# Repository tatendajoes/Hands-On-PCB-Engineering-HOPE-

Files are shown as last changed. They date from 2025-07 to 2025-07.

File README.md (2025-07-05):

# USB Charger PCB
**Mentor:** Nehemiah Edison  
**Mentee:** Tatenda Joseph

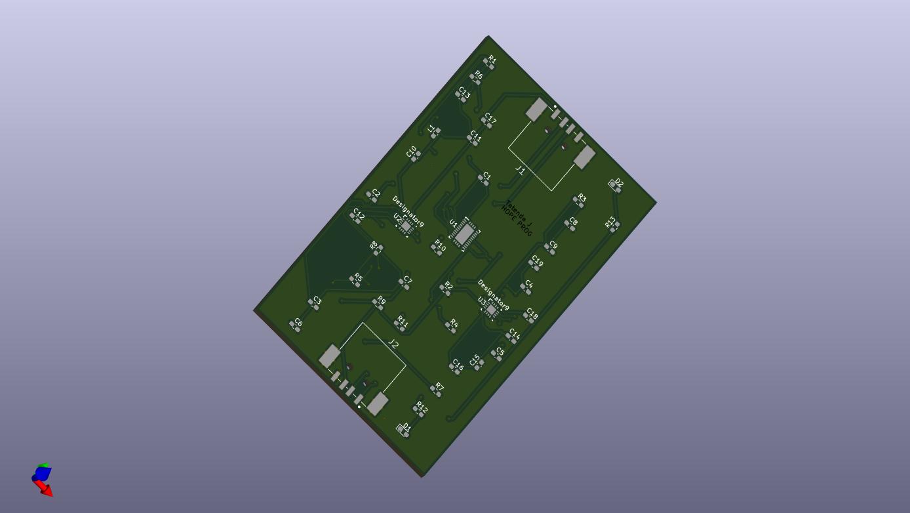
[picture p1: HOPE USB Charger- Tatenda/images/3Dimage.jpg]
3D diagram of USB charger PCB

## Overview
The project focuses on designing and developing a USB charger PCB. The primary function is to provide a regulated 5 V DC supply to charge USB devices (smartphones, tablets, etc.).

## How It Works
1. **12 V DC Input**: Accepts 12 V DC from a car battery, bench supply, or external adapter.  
2. **5 V Buck Conversion (LM73606)**: Synchronous step-down converter steps 12 V down to a regulated 5 V rail (up to 6 A).  
3. **USB Charging Port Controllers (TPS2549 × 2)**: Each USB-A port uses a TPS2549 for BC1.2 signature detection (SDP/CDP/DCP), allowing up to 1.5 A per port.  
4. **Dual-Port Output**: Each port supplies 5 V at 1.5 A (7.5 W), with both ports up to 3 A total (15 W).

## Components
- Capacitors (various values) – 19 total  
- LEDs (BLUE CLEAR SMD R/A) – 2  
- USB Connectors – 2  
- Inductor (Iron-core) – 1  
- Resistors (various values and types) – 13 total  
- LM73606 switching regulator IC – 1  
- TPS2549 IC (BC1.2 port controller) – 2

## Use Cases
- Charging smartphones and tablets (BC1.2-compliant devices, up to 1.5 A)  
- Powering USB modules (Arduinos, ESP32, Raspberry Pi Zero, sensors)  
- Converting 12 V to 5 V for bench or automotive applications

## Objectives
- Design schematic in KiCad and assign footprints  
- Run ERC and complete PCB layout  
- Run DRC and generate Gerbers  
- Create BOM and submit to Oshpark  
- Order parts from DigiKey and assemble PCB  
- Test and validate performance

## Schematic

- Schematic Diagram
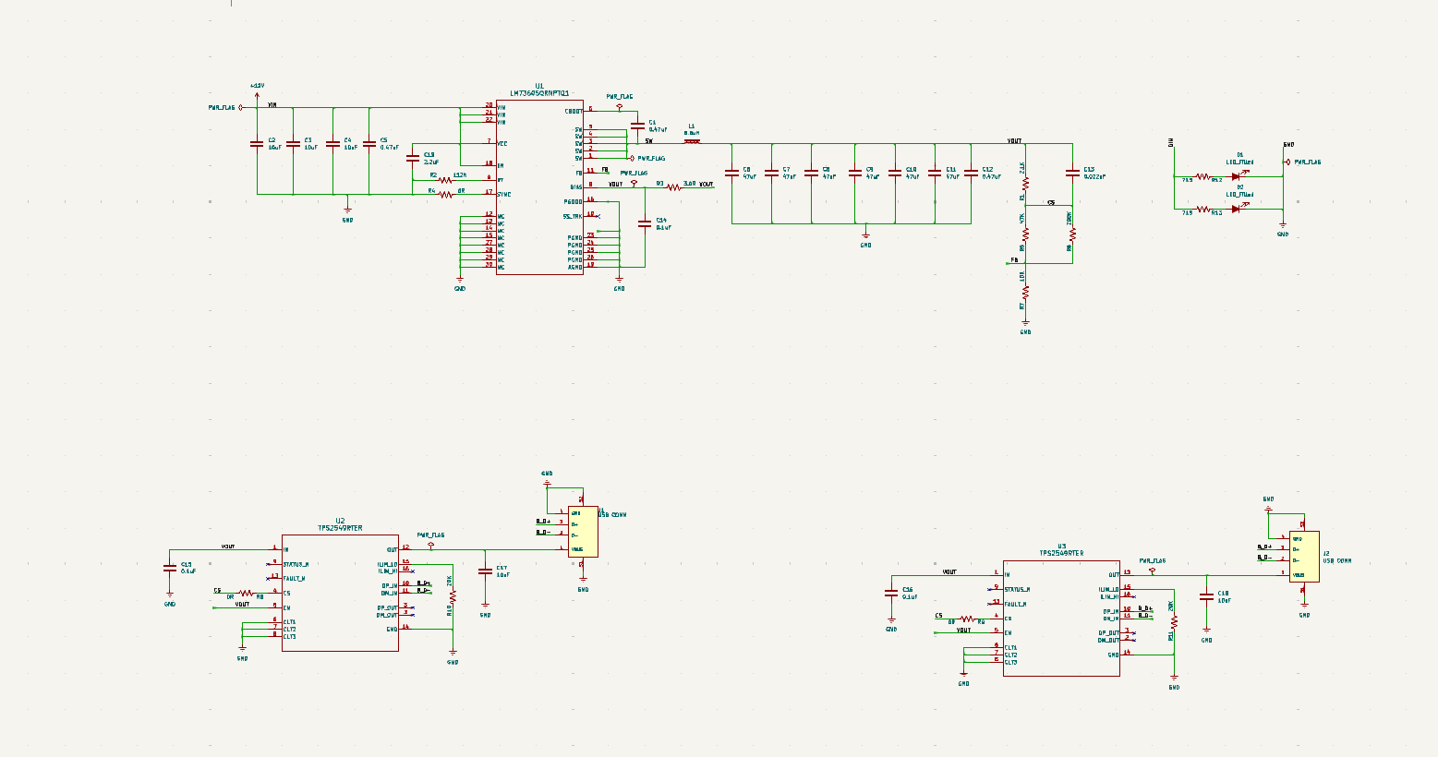
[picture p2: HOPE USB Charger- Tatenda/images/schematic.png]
shematic diagram of USB charger PCB


- PCB Diagram
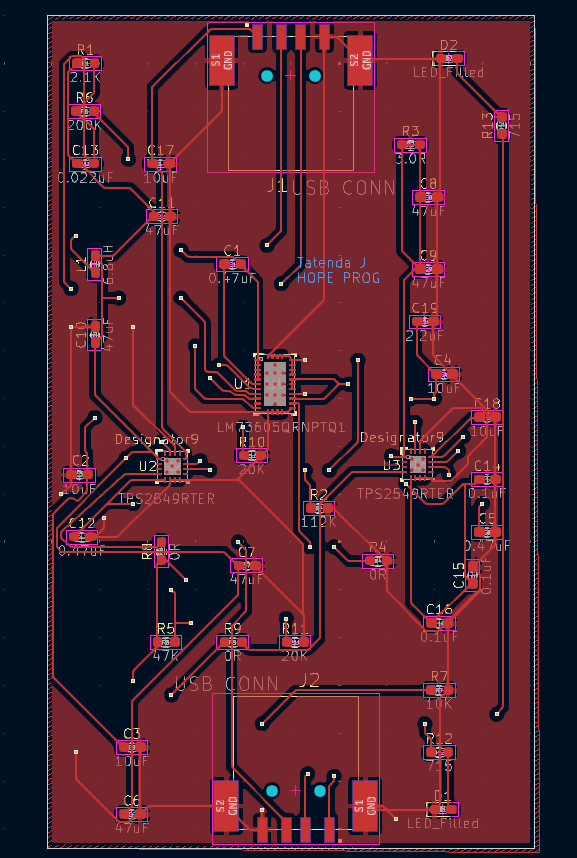
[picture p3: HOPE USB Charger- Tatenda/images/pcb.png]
pcb diagram of USB charger PCB


## Specifications
| Parameter | Specification |
|---|---|
| **Input** | |
| Voltage range | 9 – 18 V DC |
| Maximum input current | 4 A (at Vin under full load)  |
| **Power Conversion**  | |
| Converter IC | LM73606 |
| Typical efficiency | ~90% at 3 A |
| **Output (per port)** | |
| Voltage | 5.00 V ± 1% |
| Max current | 1.5 A |
| **Combined output** | |
| Total max current | 3.0 A |
| **Port controller** | |
| Controller IC | TPS2549 × 2 |
| BC1.2 signatures | SDP / CDP / DCP |
| **Environmental** | |
| Operating temperature | –40 °C to +85 °C |
| **PCB** | |
| Layers & material | 2-layer FR-4 (1.6 mm) |
| Dimensions | 60 mm × 40 mm (approx.) |

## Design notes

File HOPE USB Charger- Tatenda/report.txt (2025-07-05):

Info: Processing symbol 'C1:Capacitor_SMD:C_0603_1608Metric_Pad1.08x0.95mm_HandSolder'.
Info: Processing symbol 'C14:Capacitor_SMD:C_0603_1608Metric_Pad1.08x0.95mm_HandSolder'.
Info: Processing symbol 'C4:Capacitor_SMD:C_0603_1608Metric_Pad1.08x0.95mm_HandSolder'.
Info: Processing symbol 'C13:Capacitor_SMD:C_0603_1608Metric_Pad1.08x0.95mm_HandSolder'.
Info: Processing symbol 'C9:Capacitor_SMD:C_0603_1608Metric_Pad1.08x0.95mm_HandSolder'.
Info: Processing symbol 'C8:Capacitor_SMD:C_0603_1608Metric_Pad1.08x0.95mm_HandSolder'.
Info: Processing symbol 'C10:Capacitor_SMD:C_0603_1608Metric_Pad1.08x0.95mm_HandSolder'.
Info: Processing symbol 'C7:Capacitor_SMD:C_0603_1608Metric_Pad1.08x0.95mm_HandSolder'.
Info: Processing symbol 'C3:Capacitor_SMD:C_0603_1608Metric_Pad1.08x0.95mm_HandSolder'.
Info: Processing symbol 'C19:Capacitor_SMD:C_0603_1608Metric_Pad1.08x0.95mm_HandSolder'.
Info: Processing symbol 'C6:Capacitor_SMD:C_0603_1608Metric_Pad1.08x0.95mm_HandSolder'.
Info: Processing symbol 'C11:Capacitor_SMD:C_0603_1608Metric_Pad1.08x0.95mm_HandSolder'.
Info: Processing symbol 'C15:Capacitor_SMD:C_0603_1608Metric_Pad1.08x0.95mm_HandSolder'.
Info: Processing symbol 'C2:Capacitor_SMD:C_0603_1608Metric_Pad1.08x0.95mm_HandSolder'.
Info: Processing symbol 'C18:Capacitor_SMD:C_0603_1608Metric_Pad1.08x0.95mm_HandSolder'.
Info: Processing symbol 'C5:Capacitor_SMD:C_0603_1608Metric_Pad1.08x0.95mm_HandSolder'.
Info: Processing symbol 'C12:Capacitor_SMD:C_0603_1608Metric_Pad1.08x0.95mm_HandSolder'.
Info: Processing symbol 'C16:Capacitor_SMD:C_0603_1608Metric_Pad1.08x0.95mm_HandSolder'.
Info: Processing symbol 'C17:Capacitor_SMD:C_0603_1608Metric_Pad1.08x0.95mm_HandSolder'.
Info: Processing symbol 'D1:Diode_SMD:D_0603_1608Metric_Pad1.05x0.95mm_HandSolder'.
Info: Processing symbol 'D2:Diode_SMD:D_0603_1608Metric_Pad1.05x0.95mm_HandSolder'.
Info: Processing symbol 'J1:AAMU Senior Design 2024-25:CUI_UJ2-AH-1-SMT'.
Info: Processing symbol 'J2:AAMU Senior Design 2024-25:CUI_UJ2-AH-1-SMT'.
Info: Processing symbol 'L1:Inductor_SMD:L_0603_1608Metric_Pad1.05x0.95mm_HandSolder'.
Info: Processing symbol 'R1:Resistor_SMD:R_0603_1608Metric_Pad0.98x0.95mm_HandSolder'.
Info: Processing symbol 'R2:Resistor_SMD:R_0603_1608Metric_Pad0.98x0.95mm_HandSolder'.
Info: Processing symbol 'R3:Resistor_SMD:R_0603_1608Metric_Pad0.98x0.95mm_HandSolder'.
Info: Processing symbol 'R4:Resistor_SMD:R_0603_1608Metric_Pad0.98x0.95mm_HandSolder'.
Info: Processing symbol 'R5:Resistor_SMD:R_0603_1608Metric_Pad0.98x0.95mm_HandSolder'.
Info: Processing symbol 'R6:Resistor_SMD:R_0603_1608Metric_Pad0.98x0.95mm_HandSolder'.
Info: Processing symbol 'R7:Resistor_SMD:R_0603_1608Metric_Pad0.98x0.95mm_HandSolder'.
Info: Processing symbol 'R8:Resistor_SMD:R_0603_1608Metric_Pad0.98x0.95mm_HandSolder'.
Info: Processing symbol 'R9:Resistor_SMD:R_0603_1608Metric_Pad0.98x0.95mm_HandSolder'.
Info: Processing symbol 'R10:Resistor_SMD:R_0603_1608Metric_Pad0.98x0.95mm_HandSolder'.
Info: Processing symbol 'R11:Resistor_SMD:R_0603_1608Metric_Pad0.98x0.95mm_HandSolder'.
Info: Processing symbol 'R12:Resistor_SMD:R_0603_1608Metric_Pad0.98x0.95mm_HandSolder'.
Info: Processing symbol 'R13:Resistor_SMD:R_0603_1608Metric_Pad0.98x0.95mm_HandSolder'.
Info: Processing symbol 'U1:AAMU Senior Design 2024-25:RNP0030A'.
Info: Processing symbol 'U2:AAMU Senior Design 2024-25:RTE0016C'.
Info: Processing symbol 'U3:AAMU Senior Design 2024-25:RTE0016C'.
Connected C2 pin 2 to GND.
Add net +12V.
Connected C2 pin 1 to +12V.
Added C3 (footprint 'Capacitor_SMD:C_0603_1608Metric_Pad1.08x0.95mm_HandSolder').
Changed REF** reference designator to C3.
Changed C3 value from C_0603_1608Metric_Pad1.08x0.95mm_HandSolder to 10uF.
Updated C3 symbol association from  to /19286bda-7a7a-4466-992b-d0f40b0c6c4e.
Updated C3 fields.
Updated C3 sheetname to 'Root'.
Updated C3 sheetfile to 'HOPE USB Charger- Tatenda.kicad_sch'.
Updated C3 footprint filters to 'C_*'.
Connected C3 pin 1 to +12V.
Connected C3 pin 2 to GND.
Added C4 (footprint 'Capacitor_SMD:C_0603_1608Metric_Pad1.08x0.95mm_HandSolder').
Changed REF** reference designator to C4.
Changed C4 value from C_0603_1608Metric_Pad1.08x0.95mm_HandSolder to 10uF.
Updated C4 symbol association from  to /04ccd5c6-15b2-4030-945e-ed818584f25c.
Updated C4 fields.
Updated C4 sheetname to 'Root'.
Updated C4 sheetfile to 'HOPE USB Charger- Tatenda.kicad_sch'.
Updated C4 footprint filters to 'C_*'.
Connected C4 pin 1 to +12V.
Connected C4 pin 2 to GND.
Added C5 (footprint 'Capacitor_SMD:C_0603_1608Metric_Pad1.08x0.95mm_HandSolder').
Changed REF** reference designator to C5.
Changed C5 value from C_0603_1608Metric_Pad1.08x0.95mm_HandSolder to 0.47uF.
Updated C5 symbol association from  to /ef5993d3-073b-4f01-b6a1-0fe2b9706ae6.
Updated C5 fields.
Updated C5 sheetname to 'Root'.
Updated C5 sheetfile to 'HOPE USB Charger- Tatenda.kicad_sch'.
Updated C5 footprint filters to 'C_*'.
Connected C5 pin 1 to +12V.
Connected C5 pin 2 to GND.
Added C6 (footprint 'Capacitor_SMD:C_0603_1608Metric_Pad1.08x0.95mm_HandSolder').
Changed REF** reference designator to C6.
Changed C6 value from C_0603_1608Metric_Pad1.08x0.95mm_HandSolder to 47uF.
Updated C6 symbol association from  to /00fe3671-6971-4a1d-9a66-dda608e3093a.
Updated C6 fields.
Updated C6 sheetname to 'Root'.
Updated C6 sheetfile to 'HOPE USB Charger- Tatenda.kicad_sch'.
Updated C6 footprint filters to 'C_*'.
Connected C6 pin 2 to GND.
Add net /VOUT.
Connected C6 pin 1 to /VOUT.
Added C7 (footprint 'Capacitor_SMD:C_0603_1608Metric_Pad1.08x0.95mm_HandSolder').
Changed REF** reference designator to C7.
Changed C7 value from C_0603_1608Metric_Pad1.08x0.95mm_HandSolder to 47uF.
Updated C7 symbol association from  to /8db145ac-a443-40e6-a1bf-7e9539908e10.
Updated C7 fields.
Updated C7 sheetname to 'Root'.
Updated C7 sheetfile to 'HOPE USB Charger- Tatenda.kicad_sch'.
Updated C7 footprint filters to 'C_*'.
Connected C7 pin 1 to /VOUT.
Connected C7 pin 2 to GND.
Added C8 (footprint 'Capacitor_SMD:C_0603_1608Metric_Pad1.08x0.95mm_HandSolder').
Changed REF** reference designator to C8.
Changed C8 value from C_0603_1608Metric_Pad1.08x0.95mm_HandSolder to 47uF.
Updated C8 symbol association from  to /60575305-37fa-4438-99a9-70368577a35f.
Updated C8 fields.
Updated C8 sheetname to 'Root'.
Updated C8 sheetfile to 'HOPE USB Charger- Tatenda.kicad_sch'.
Updated C8 footprint filters to 'C_*'.
Connected C8 pin 1 to /VOUT.
Connected C8 pin 2 to GND.
Added C9 (footprint 'Capacitor_SMD:C_0603_1608Metric_Pad1.08x0.95mm_HandSolder').
Changed REF** reference designator to C9.
Changed C9 value from C_0603_1608Metric_Pad1.08x0.95mm_HandSolder to 47uF.
Updated C9 symbol association from  to /c17b6783-4fc2-4924-acce-468ea2bac7e7.
Updated C9 fields.
Updated C9 sheetname to 'Root'.
Updated C9 sheetfile to 'HOPE USB Charger- Tatenda.kicad_sch'.
Updated C9 footprint filters to 'C_*'.
Connected C9 pin 2 to GND.
Connected C9 pin 1 to /VOUT.
Added C10 (footprint 'Capacitor_SMD:C_0603_1608Metric_Pad1.08x0.95mm_HandSolder').
Changed REF** reference designator to C10.
Changed C10 value from C_0603_1608Metric_Pad1.08x0.95mm_HandSolder to 47uF.
Updated C10 symbol association from  to /0f25906a-1385-4035-a5d8-c43b97dbfe95.
Updated C10 fields.
Updated C10 sheetname to 'Root'.
Updated C10 sheetfile to 'HOPE USB Charger- Tatenda.kicad_sch'.
Updated C10 footprint filters to 'C_*'.
Connected C10 pin 2 to GND.
Connected C10 pin 1 to /VOUT.
Added C11 (footprint 'Capacitor_SMD:C_0603_1608Metric_Pad1.08x0.95mm_HandSolder').
Changed REF** reference designator to C11.
Changed C11 value from C_0603_1608Metric_Pad1.08x0.95mm_HandSolder to 47uF.
Updated C11 symbol association from  to /2349d69c-5e6f-4ee1-b4f1-8996a50e921d.
Updated C11 fields.
Updated C11 sheetname to 'Root'.
Updated C11 sheetfile to 'HOPE USB Charger- Tatenda.kicad_sch'.
Updated C11 footprint filters to 'C_*'.
Connected C11 pin 1 to /VOUT.
Connected C11 pin 2 to GND.
Added C12 (footprint 'Capacitor_SMD:C_0603_1608Metric_Pad1.08x0.95mm_HandSolder').
Changed REF** reference designator to C12.
Changed C12 value from C_0603_1608Metric_Pad1.08x0.95mm_HandSolder to 0.47uF.
Updated C12 symbol association from  to /210c44ad-f5fc-4b04-afed-6277b7e008d1.
Updated C12 fields.
Updated C12 sheetname to 'Root'.
Updated C12 sheetfile to 'HOPE USB Charger- Tatenda.kicad_sch'.
Updated C12 footprint filters to 'C_*'.
Connected C12 pin 2 to GND.
Connected C12 pin 1 to /VOUT.
Added C13 (footprint 'Capacitor_SMD:C_0603_1608Metric_Pad1.08x0.95mm_HandSolder').
Changed REF** reference designator to C13.
Changed C13 value from C_0603_1608Metric_Pad1.08x0.95mm_HandSolder to 0.022uF.
Updated C13 symbol association from  to /689d0605-5dd5-4adc-8e06-5128acd837bf.
Updated C13 fields.
Updated C13 sheetname to 'Root'.
Updated C13 sheetfile to 'HOPE USB Charger- Tatenda.kicad_sch'.
Updated C13 footprint filters to 'C_*'.
Connected C13 pin 1 to /VOUT.
Add net /CS.
Connected C13 pin 2 to /CS.
Added C14 (footprint 'Capacitor_SMD:C_0603_1608Metric_Pad1.08x0.95mm_HandSolder').
Changed REF** reference designator to C14.
Changed C14 value from C_0603_1608Metric_Pad1.08x0.95mm_HandSolder to 0.1uF.
Updated C14 symbol association from  to /54368b59-0083-4ce2-8e27-e1faf3f807eb.
Updated C14 fields.
Updated C14 sheetfile to 'HOPE USB Charger- Tatenda.kicad_sch'.
Updated C14 footprint filters to 'C_*'.
Connected C14 pin 1 to /VOUT.
Connected C14 pin 2 to GND.
Added C15 (footprint 'Capacitor_SMD:C_0603_1608Metric_Pad1.08x0.95mm_HandSolder').
Changed REF** reference designator to C15.
Changed C15 value from C_0603_1608Metric_Pad1.08x0.95mm_HandSolder to 0.1uF.
Updated C15 symbol association from  to /e1a83c1a-e9d5-4eb2-84d7-cf7e96ed6b5c.
Updated C15 fields.
Updated C15 sheetname to 'Root'.
Updated C15 sheetfile to 'HOPE USB Charger- Tatenda.kicad_sch'.
Updated C15 footprint filters to 'C_*'.
Connected C15 pin 1 to /VOUT.
Connected C15 pin 2 to GND.
Added C16 (footprint 'Capacitor_SMD:C_0603_1608Metric_Pad1.08x0.95mm_HandSolder').
Changed REF** reference designator to C16.
Changed C16 value from C_0603_1608Metric_Pad1.08x0.95mm_HandSolder to 0.1uF.
Updated C16 symbol association from  to /3e55ec13-5c51-4087-b657-3464082d02a5.
Updated C16 fields.
Updated C16 sheetname to 'Root'.
Updated C16 sheetfile to 'HOPE USB Charger- Tatenda.kicad_sch'.
Updated C16 footprint filters to 'C_*'.
Connected C16 pin 1 to /VOUT.
Connected C16 pin 2 to GND.
Added C17 (footprint 'Capacitor_SMD:C_0603_1608Metric_Pad1.08x0.95mm_HandSolder').
Changed REF** reference designator to C17.
Changed C17 value from C_0603_1608Metric_Pad1.08x0.95mm_HandSolder to 10uF.
Updated C17 symbol association from  to /3fcb8ce3-75a4-4dc4-8ae5-304c34109ee5.
Updated C17 fields.
Updated C17 sheetname to 'Root'.
Updated C17 sheetfile to 'HOPE USB Charger- Tatenda.kicad_sch'.
Updated C17 footprint filters to 'C_*'.
Connected C17 pin 2 to GND.
Add net Net-(J1-VBUS).
Connected C17 pin 1 to Net-(J1-VBUS).
Added C18 (footprint 'Capacitor_SMD:C_0603_1608Metric_Pad1.08x0.95mm_HandSolder').
Changed REF** reference designator to C18.
Changed C18 value from C_0603_1608Metric_Pad1.08x0.95mm_HandSolder to 10uF.
Updated C18 symbol association from  to /bf8fe8a2-7e39-4c4e-be99-1289ef0bbc39.
Updated C18 fields.
Updated C18 sheetname to 'Root'.
Updated C18 sheetfile to 'HOPE USB Charger- Tatenda.kicad_sch'.
Updated C18 footprint filters to 'C_*'.
Add net Net-(J2-VBUS).
Connected C18 pin 1 to Net-(J2-VBUS).
Connected C18 pin 2 to GND.
Updated C14 sheetname to 'Root'.
Added C19 (footprint 'Capacitor_SMD:C_0603_1608Metric_Pad1.08x0.95mm_HandSolder').
Changed REF** reference designator to C19.
Changed C19 value from C_0603_1608Metric_Pad1.08x0.95mm_HandSolder to 2.2uF.
Updated C19 symbol association from  to /f62714eb-9b48-4dca-be03-ad18b1f4418e.
Updated C19 fields.
Updated C19 sheetname to 'Root'.
Updated C19 sheetfile to 'HOPE USB Charger- Tatenda.kicad_sch'.
Updated C19 footprint filters to 'C_*'.
Connected C19 pin 2 to GND.
Connected C19 pin 1 to +12V.
Added C1 (footprint 'Capacitor_SMD:C_0603_1608Metric_Pad1.08x0.95mm_HandSolder').
Added D1 (footprint 'Diode_SMD:D_0603_1608Metric_Pad1.05x0.95mm_HandSolder').
Changed REF** reference designator to D1.
Changed D1 value from D_0603_1608Metric_Pad1.05x0.95mm_HandSolder to LED_Filled.
Updated D1 symbol association from  to /e141c6f9-6236-4e4f-9423-103b54fd7a2f.
Updated D1 fields.
Updated D1 sheetname to 'Root'.
Updated D1 sheetfile to 'HOPE USB Charger- Tatenda.kicad_sch'.
Updated D1 footprint filters to 'LED* LED_SMD:* LED_THT:*'.
Add net Net-(D1-A).
Connected D1 pin 2 to Net-(D1-A).
Connected D1 pin 1 to GND.
Changed REF** reference designator to C1.
Added D2 (footprint 'Diode_SMD:D_0603_1608Metric_Pad1.05x0.95mm_HandSolder').
Changed REF** reference designator to D2.
Changed D2 value from D_0603_1608Metric_Pad1.05x0.95mm_HandSolder to LED_Filled.
Updated D2 symbol association from  to /46838bdf-4686-4594-9151-cc60d0690727.
Updated D2 fields.
Updated D2 sheetname to 'Root'.
Updated D2 sheetfile to 'HOPE USB Charger- Tatenda.kicad_sch'.
Updated D2 footprint filters to 'LED* LED_SMD:* LED_THT:*'.
Add net Net-(D2-A).
Connected D2 pin 2 to Net-(D2-A).
Connected D2 pin 1 to GND.
Changed C1 value from C_0603_1608Metric_Pad1.08x0.95mm_HandSolder to 0.47uF.
Updated C1 symbol association from  to /335372d9-3a5d-4d5a-a8b4-353cd66d1977.
Updated C1 fields.
Added L1 (footprint 'Inductor_SMD:L_0603_1608Metric_Pad1.05x0.95mm_HandSolder').
Changed REF** reference designator to L1.
Changed L1 value from L_0603_1608Metric_Pad1.05x0.95mm_HandSolder to 6.8uH.
Updated L1 symbol association from  to /37fa4ad2-6970-476d-abc9-2c8cad30b114.
Updated L1 fields.
Updated L1 sheetname to 'Root'.
Updated L1 sheetfile to 'HOPE USB Charger- Tatenda.kicad_sch'.
Updated L1 footprint filters to 'Choke_* *Coil* Inductor_* L_*'.
Connected L1 pin 2 to /VOUT.
Connected L1 pin 1 to /SW.
Updated C1 sheetname to 'Root'.
Added R1 (footprint 'Resistor_SMD:R_0603_1608Metric_Pad0.98x0.95mm_HandSolder').
Changed REF** reference designator to R1.
Changed R1 value from R_0603_1608Metric_Pad0.98x0.95mm_HandSolder to 2.1K.
Updated R1 symbol association from  to /0eba38ee-2483-4a1f-a93c-bf059771c4f2.
Updated R1 fields.
Updated R1 sheetname to 'Root'.
Updated R1 sheetfile to 'HOPE USB Charger- Tatenda.kicad_sch'.
Updated R1 footprint filters to 'R_*'.
Connected R1 pin 2 to /CS.
Connected R1 pin 1 to /VOUT.
Updated C1 sheetfile to 'HOPE USB Charger- Tatenda.kicad_sch'.
Added R2 (footprint 'Resistor_SMD:R_0603_1608Metric_Pad0.98x0.95mm_HandSolder').
Changed REF** reference designator to R2.
Changed R2 value from R_0603_1608Metric_Pad0.98x0.95mm_HandSolder to 112K.
Updated R2 symbol association from  to /35ce431e-2ae0-4e6b-9935-65c3c85fc5c0.
Updated R2 fields.
Updated R2 sheetname to 'Root'.
Updated R2 sheetfile to 'HOPE USB Charger- Tatenda.kicad_sch'.
Updated R2 footprint filters to 'R_*'.
Connected R2 pin 2 to GND.
Add net Net-(U1-RT).
Connected R2 pin 1 to Net-(U1-RT).
Updated C1 footprint filters to 'C_*'.
Added R3 (footprint 'Resistor_SMD:R_0603_1608Metric_Pad0.98x0.95mm_HandSolder').
Changed REF** reference designator to R3.
Changed R3 value from R_0603_1608Metric_Pad0.98x0.95mm_HandSolder to 3.0R.
Updated R3 symbol association from  to /b5b9785f-a7e4-41e9-a2fe-aed746a44e0d.
Updated R3 fields.
Updated R3 sheetname to 'Root'.
Updated R3 sheetfile to 'HOPE USB Charger- Tatenda.kicad_sch'.
Updated R3 footprint filters to 'R_*'.
Connected R3 pin 1 to /VOUT.
Connected R3 pin 2 to /VOUT.
Add net Net-(U1-CBOOT).
Added R4 (footprint 'Resistor_SMD:R_0603_1608Metric_Pad0.98x0.95mm_HandSolder').
Changed REF** reference designator to R4.
Changed R4 value from R_0603_1608Metric_Pad0.98x0.95mm_HandSolder to 0R.
Updated R4 symbol association from  to /766dea5a-03ff-4513-90cd-af29e92f0ade.
Updated R4 fields.
Updated R4 sheetname to 'Root'.
Updated R4 sheetfile to 'HOPE USB Charger- Tatenda.kicad_sch'.
Updated R4 footprint filters to 'R_*'.
Add net Net-(U1-SYNC).
Connected R4 pin 1 to Net-(U1-SYNC).
Connected R4 pin 2 to GND.
Connected C1 pin 1 to Net-(U1-CBOOT).
Added R5 (footprint 'Resistor_SMD:R_0603_1608Metric_Pad0.98x0.95mm_HandSolder').
Changed REF** reference designator to R5.
Changed R5 value from R_0603_1608Metric_Pad0.98x0.95mm_HandSolder to 47K.
Updated R5 symbol association from  to /3486b6a7-176e-468b-bf43-bdb705569e36.
Updated R5 fields.
Updated R5 sheetname to 'Root'.
Updated R5 sheetfile to 'HOPE USB Charger- Tatenda.kicad_sch'.
Updated R5 footprint filters to 'R_*'.
Connected R5 pin 1 to /CS.
Add net /FB.
Connected R5 pin 2 to /FB.
Add net /SW.
Added R6 (footprint 'Resistor_SMD:R_0603_1608Metric_Pad0.98x0.95mm_HandSolder').
Changed REF** reference designator to R6.
Changed R6 value from R_0603_1608Metric_Pad0.98x0.95mm_HandSolder to 200K.
Updated R6 symbol association from  to /e81fb007-7ae9-4c03-9c0f-d92360785fff.
Updated R6 fields.
Updated R6 sheetname to 'Root'.
Updated R6 sheetfile to 'HOPE USB Charger- Tatenda.kicad_sch'.
Updated R6 footprint filters to 'R_*'.
Connected R6 pin 2 to /FB.
Connected R6 pin 1 to /CS.
Connected C1 pin 2 to /SW.
Added R7 (footprint 'Resistor_SMD:R_0603_1608Metric_Pad0.98x0.95mm_HandSolder').
Changed REF** reference designator to R7.
Changed R7 value from R_0603_1608Metric_Pad0.98x0.95mm_HandSolder to 10K.
Updated R7 symbol association from  to /892a2c66-8db2-4780-a052-6eef2fc0a6a8.
Updated R7 fields.
Updated R7 sheetname to 'Root'.
Updated R7 sheetfile to 'HOPE USB Charger- Tatenda.kicad_sch'.
Updated R7 footprint filters to 'R_*'.
Connected R7 pin 1 to /FB.
Connected R7 pin 2 to GND.
Added C2 (footprint 'Capacitor_SMD:C_0603_1608Metric_Pad1.08x0.95mm_HandSolder').
Added R8 (footprint 'Resistor_SMD:R_0603_1608Metric_Pad0.98x0.95mm_HandSolder').
Changed REF** reference designator to R8.
Changed R8 value from R_0603_1608Metric_Pad0.98x0.95mm_HandSolder to 0R.
Updated R8 symbol association from  to /d2c124ac-7850-4621-9b2c-24e613d258bc.
Updated R8 fields.
Updated R8 sheetname to 'Root'.
Updated R8 sheetfile to 'HOPE USB Charger- Tatenda.kicad_sch'.
Updated R8 footprint filters to 'R_*'.
Connected R8 pin 1 to /CS.
Add net Net-(U2-CS).
Connected R8 pin 2 to Net-(U2-CS).
Changed REF** reference designator to C2.
Added R9 (footprint 'Resistor_SMD:R_0603_1608Metric_Pad0.98x0.95mm_HandSolder').
Changed REF** reference designator to R9.
Changed R9 value from R_0603_1608Metric_Pad0.98x0.95mm_HandSolder to 0R.
Updated R9 symbol association from  to /f95fb09a-5959-45ad-aa9c-b73250de8db6.
Updated R9 fields.
Updated R9 sheetname to 'Root'.
Updated R9 sheetfile to 'HOPE USB Charger- Tatenda.kicad_sch'.
Updated R9 footprint filters to 'R_*'.
Connected R9 pin 1 to /CS.
Add net Net-(U3-CS).
Connected R9 pin 2 to Net-(U3-CS).
Changed C2 value from C_0603_1608Metric_Pad1.08x0.95mm_HandSolder to 10uF.
Added R10 (footprint 'Resistor_SMD:R_0603_1608Metric_Pad0.98x0.95mm_HandSolder').
Changed REF** reference designator to R10.
Changed R10 value from R_0603_1608Metric_Pad0.98x0.95mm_HandSolder to 20K.
Updated R10 symbol association from  to /c2334109-bf59-453b-b08c-01f0eb29283c.
Updated R10 fields.
Updated R10 sheetname to 'Root'.
Updated R10 sheetfile to 'HOPE USB Charger- Tatenda.kicad_sch'.
Updated R10 footprint filters to 'R_*'.
Connected R10 pin 2 to GND.
Add net Net-(U2-ILIM_LO).
Connected R10 pin 1 to Net-(U2-ILIM_LO).
Updated C2 symbol association from  to /327b265e-bf1d-4c05-9ce4-4cd48b15e5ac.
Added R11 (footprint 'Resistor_SMD:R_0603_1608Metric_Pad0.98x0.95mm_HandSolder').
Changed REF** reference designator to R11.
Changed R11 value from R_0603_1608Metric_Pad0.98x0.95mm_HandSolder to 20K.
Updated R11 symbol association from  to /95875f8f-b52c-4588-a41e-5449f336b5ed.
Updated R11 fields.
Updated R11 sheetname to 'Root'.
Updated R11 sheetfile to 'HOPE USB Charger- Tatenda.kicad_sch'.
Updated R11 footprint filters to 'R_*'.
Connected R11 pin 2 to GND.
Add net Net-(U3-ILIM_LO).
Connected R11 pin 1 to Net-(U3-ILIM_LO).
Updated C2 fields.
Added R12 (footprint 'Resistor_SMD:R_0603_1608Metric_Pad0.98x0.95mm_HandSolder').
Changed REF** reference designator to R12.
Changed R12 value from R_0603_1608Metric_Pad0.98x0.95mm_HandSolder to 715.
Updated R12 symbol association from  to /d5bc29ee-c82b-4fe7-845a-510ada208e56.
Updated R12 fields.
Updated R12 sheetname to 'Root'.
Updated R12 sheetfile to 'HOPE USB Charger- Tatenda.kicad_sch'.
Updated R12 footprint filters to 'R_*'.
Connected R12 pin 2 to Net-(D1-A).
Add net /DIM.
Connected R12 pin 1 to /DIM.
Updated C2 sheetname to 'Root'.
Added R13 (footprint 'Resistor_SMD:R_0603_1608Metric_Pad0.98x0.95mm_HandSolder').
Changed REF** reference designator to R13.
Changed R13 value from R_0603_1608Metric_Pad0.98x0.95mm_HandSolder to 715.
Updated R13 symbol association from  to /5c4f9f64-80ce-4307-932f-d32ab01887b4.
Updated R13 fields.
Updated R13 sheetname to 'Root'.
Updated R13 sheetfile to 'HOPE USB Charger- Tatenda.kicad_sch'.
Updated R13 footprint filters to 'R_*'.
Connected R13 pin 1 to /DIM.
Connected R13 pin 2 to Net-(D2-A).
Updated C2 sheetfile to 'HOPE USB Charger- Tatenda.kicad_sch'.
Updated C2 footprint filters to 'C_*'.
Add net GND.
Error: Cannot add U1 (footprint 'AAMU Senior Design 2024-25:RNP0030A' not found).
Error: Cannot add J2 (footprint 'AAMU Senior Design 2024-25:CUI_UJ2-AH-1-SMT' not found).
Error: Cannot add U2 (footprint 'AAMU Senior Design 2024-25:RTE0016C' not found).
Error: Cannot add J1 (footprint 'AAMU Senior Design 2024-25:CUI_UJ2-AH-1-SMT' not found).
Error: Cannot add U3 (footprint 'AAMU Senior Design 2024-25:RTE0016C' not found).

Info: Total warnings: 0, errors: 5.

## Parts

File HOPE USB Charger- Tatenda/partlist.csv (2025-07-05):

Reference | Value | Datasheet | Footprint | Qty | DNP
C1,C5,C12 | 0.47uF | ~ | Capacitor_SMD:C_0603_1608Metric_Pad1.08x0.95mm_HandSolder | 3
C2,C3,C4,C17,C18 | 10uF | ~ | Capacitor_SMD:C_0603_1608Metric_Pad1.08x0.95mm_HandSolder | 5
C6,C7,C8,C9,C10,C11 | 47uF | ~ | Capacitor_SMD:C_0603_1608Metric_Pad1.08x0.95mm_HandSolder | 6
C13 | 0.022uF | ~ | Capacitor_SMD:C_0603_1608Metric_Pad1.08x0.95mm_HandSolder | 1
C14,C15,C16 | 0.1uF | ~ | Capacitor_SMD:C_0603_1608Metric_Pad1.08x0.95mm_HandSolder | 3
C19 | 2.2uF | ~ | Capacitor_SMD:C_0603_1608Metric_Pad1.08x0.95mm_HandSolder | 1
D1,D2 | LED_Filled | ~ | Diode_SMD:D_0603_1608Metric_Pad1.05x0.95mm_HandSolder | 2
J1,J2 | USB CONN |  | Library:CUI_UJ2-AH-1-SMT | 2
L1 | 6.8uH | ~ | Inductor_SMD:L_0603_1608Metric_Pad1.05x0.95mm_HandSolder | 1
R1 | 2.1K | ~ | Resistor_SMD:R_0603_1608Metric_Pad0.98x0.95mm_HandSolder | 1
R2 | 112K | ~ | Resistor_SMD:R_0603_1608Metric_Pad0.98x0.95mm_HandSolder | 1
R3 | 3.0R | ~ | Resistor_SMD:R_0603_1608Metric_Pad0.98x0.95mm_HandSolder | 1
R4,R8,R9 | 0R | ~ | Resistor_SMD:R_0603_1608Metric_Pad0.98x0.95mm_HandSolder | 3
R5 | 47K | ~ | Resistor_SMD:R_0603_1608Metric_Pad0.98x0.95mm_HandSolder | 1
R6 | 200K | ~ | Resistor_SMD:R_0603_1608Metric_Pad0.98x0.95mm_HandSolder | 1
R7 | 10K | ~ | Resistor_SMD:R_0603_1608Metric_Pad0.98x0.95mm_HandSolder | 1
R10,R11 | 20K | ~ | Resistor_SMD:R_0603_1608Metric_Pad0.98x0.95mm_HandSolder | 2
R12,R13 | 715 | ~ | Resistor_SMD:R_0603_1608Metric_Pad0.98x0.95mm_HandSolder | 2
U1 | LM73605QRNPTQ1 | LM73605QRNPTQ1 | Library:RNP0030A | 1
U2,U3 | TPS2549RTER | TPS2549RTER | Library:RTE0016C | 2

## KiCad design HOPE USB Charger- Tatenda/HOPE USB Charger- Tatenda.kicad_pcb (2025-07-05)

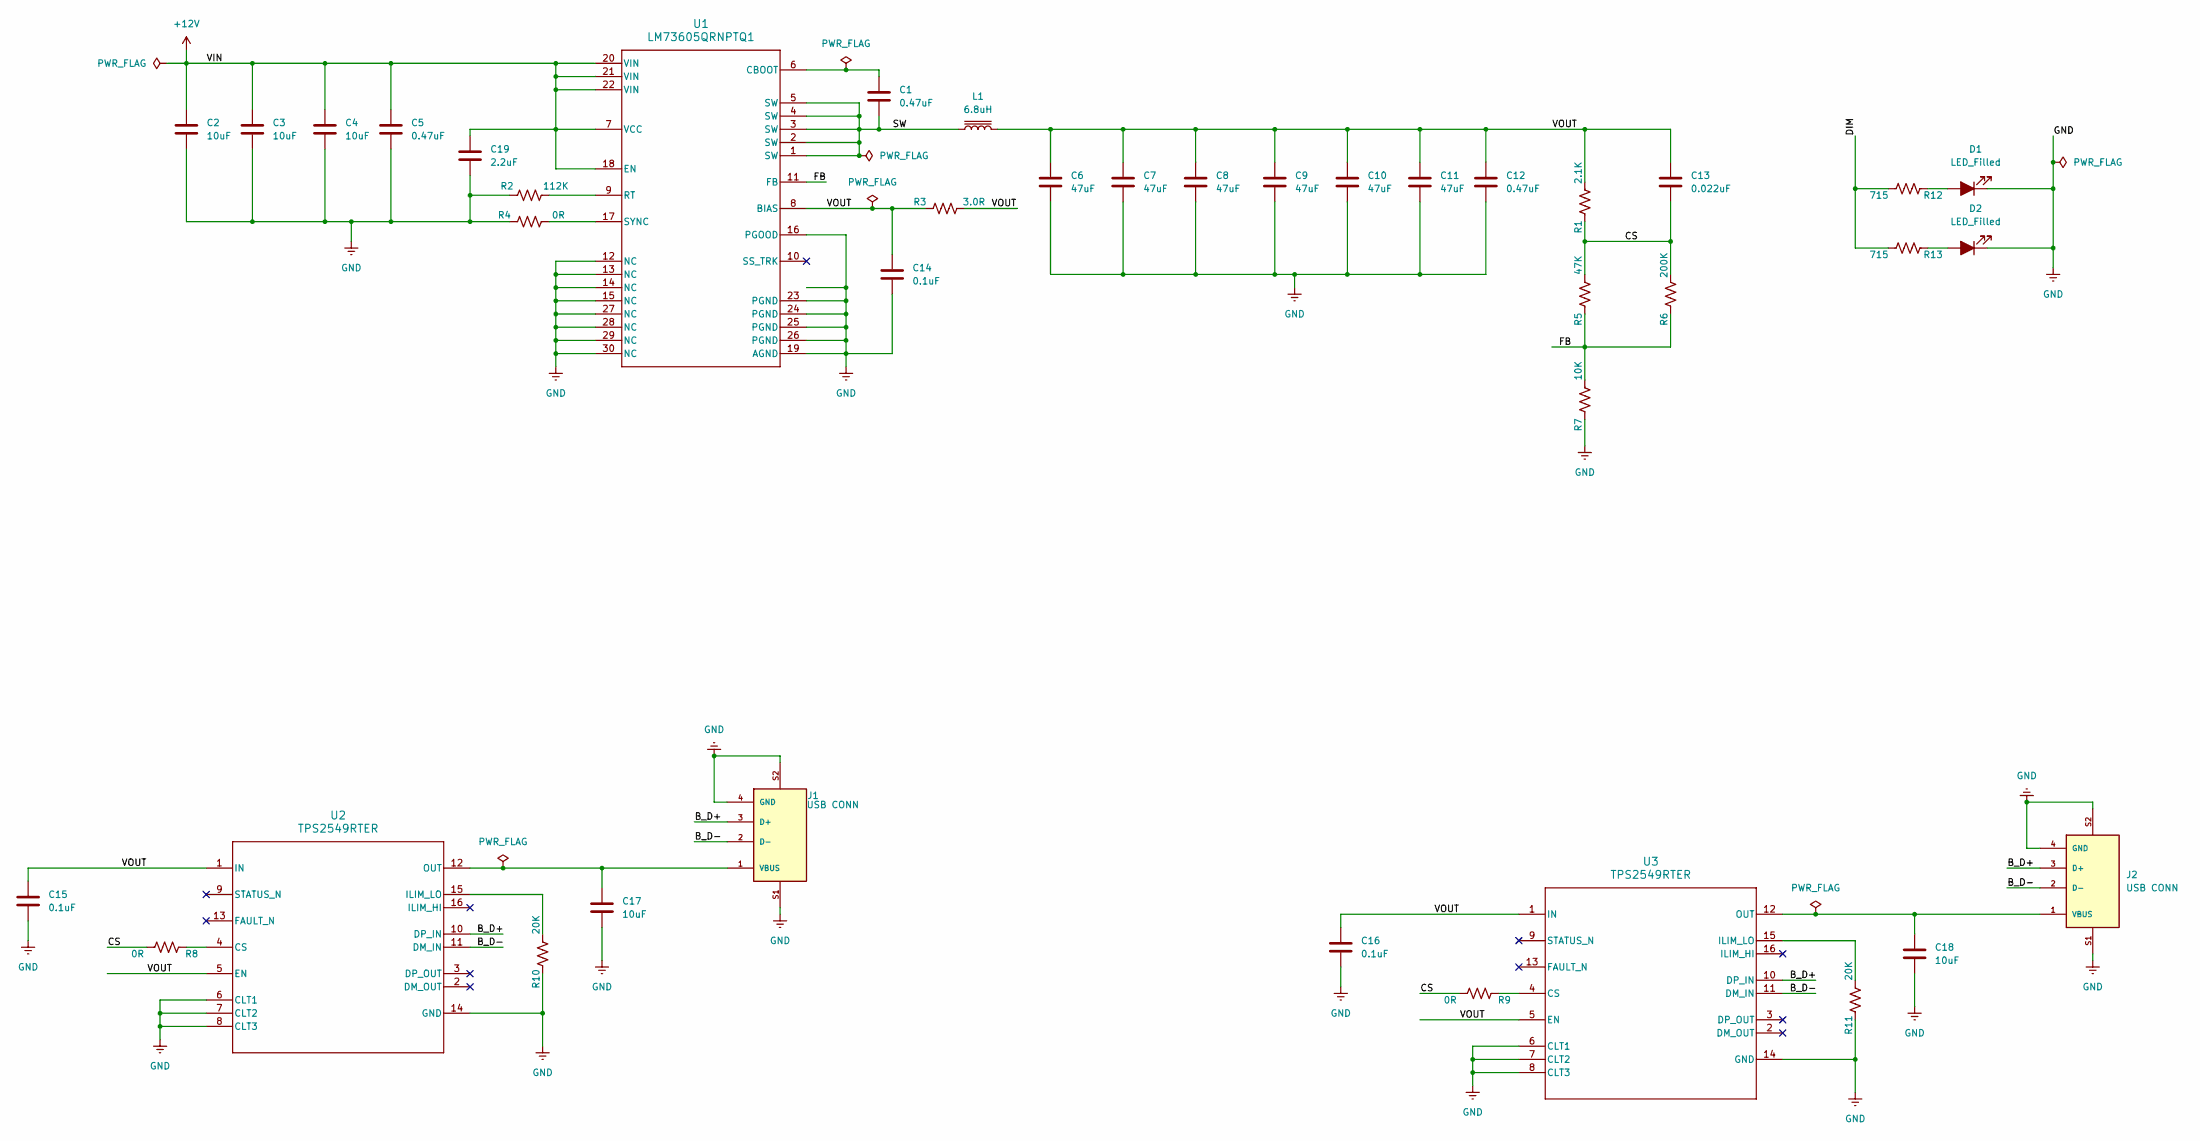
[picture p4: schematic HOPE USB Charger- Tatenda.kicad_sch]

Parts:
C1, C5, C12: 0.47uF; C_0603_1608Metric_Pad1.08x0.95mm_HandSolder
C2, C3, C4, C17, C18: 10uF; C_0603_1608Metric_Pad1.08x0.95mm_HandSolder
C6, C7, C8, C9, C10, C11: 47uF; C_0603_1608Metric_Pad1.08x0.95mm_HandSolder
C13: 0.022uF; C_0603_1608Metric_Pad1.08x0.95mm_HandSolder
C14, C15, C16: 0.1uF; C_0603_1608Metric_Pad1.08x0.95mm_HandSolder
C19: 2.2uF; C_0603_1608Metric_Pad1.08x0.95mm_HandSolder
D1, D2: LED_Filled; D_0603_1608Metric_Pad1.05x0.95mm_HandSolder
J1, J2: USB CONN; CUI_UJ2-AH-1-SMT; PARTREV 1.01
L1: 6.8uH; L_0603_1608Metric_Pad1.05x0.95mm_HandSolder
R1: 2.1K; R_0603_1608Metric_Pad0.98x0.95mm_HandSolder
R2: 112K; R_0603_1608Metric_Pad0.98x0.95mm_HandSolder
R3: 3.0R; R_0603_1608Metric_Pad0.98x0.95mm_HandSolder
R4, R8, R9: 0R; R_0603_1608Metric_Pad0.98x0.95mm_HandSolder
R5: 47K; R_0603_1608Metric_Pad0.98x0.95mm_HandSolder
R6: 200K; R_0603_1608Metric_Pad0.98x0.95mm_HandSolder
R7: 10K; R_0603_1608Metric_Pad0.98x0.95mm_HandSolder
R10, R11: 20K; R_0603_1608Metric_Pad0.98x0.95mm_HandSolder
R12, R13: 715; R_0603_1608Metric_Pad0.98x0.95mm_HandSolder
U1: LM73605QRNPTQ1; RNP0030A
U2, U3: TPS2549RTER; RTE0016C

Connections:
+12V: C2.1, C3.1, C4.1, C5.1, C19.1, U1.7 (VCC), U1.18 (EN), U1.20 (VIN), U1.21 (VIN), U1.22 (VIN)
/B_D+: J1.3 (D+), J2.3 (D+), U2.10 (DP_IN), U3.10 (DP_IN)
/B_D-: J1.2 (D-), J2.2 (D-), U2.11 (DM_IN), U3.11 (DM_IN)
/CS: C13.2, R1.2, R5.1, R6.1, R8.1, R9.1
/DIM: R12.1, R13.1
/FB: R5.2, R6.2, R7.1, U1.11 (FB)
/SW: C1.2, L1.1, U1.1 (SW), U1.2 (SW), U1.3 (SW), U1.4 (SW), U1.5 (SW)
/VOUT: C6.1, C7.1, C8.1, C9.1, C10.1, C11.1, C12.1, C13.1, C14.1, C15.1, C16.1, L1.2, R1.1, R3.1, R3.2, U1.8 (BIAS), U2.1 (IN), U2.5 (EN), U3.1 (IN), U3.5 (EN)
GND: C2.2, C3.2, C4.2, C5.2, C6.2, C7.2, C8.2, C9.2, C10.2, C11.2, C12.2, C14.2, C15.2, C16.2, C17.2, C18.2, C19.2, D1.1 (K), D2.1 (K), J1.4 (GND), J1.S1, J1.S2, J2.4 (GND), J2.S1, J2.S2, R2.2, R4.2, R7.2, R10.2, R11.2, U1.12 (NC), U1.13 (NC), U1.14 (NC), U1.15 (NC), U1.16 (PGOOD), U1.19 (AGND), U1.23 (PGND), U1.24 (PGND), U1.25 (PGND), U1.26 (PGND), U1.27 (NC), U1.28 (NC), U1.29 (NC), U1.30 (NC), U2.6 (CLT1), U2.7 (CLT2), U2.8 (CLT3), U2.14 (GND), U3.6 (CLT1), U3.7 (CLT2), U3.8 (CLT3), U3.14 (GND)
unnamed: D1.2 (A), R12.2
unnamed: D2.2 (A), R13.2
unnamed: C17.1, J1.1 (VBUS), U2.12 (OUT)
unnamed: C18.1, J2.1 (VBUS), U3.12 (OUT)
unnamed: C1.1, U1.6 (CBOOT)
unnamed: R2.1, U1.9 (RT)
unnamed: R4.1, U1.17 (SYNC)
unnamed: R8.2, U2.4 (CS)
unnamed: R10.1, U2.15 (ILIM_LO)
unnamed: R9.2, U3.4 (CS)
unnamed: R11.1, U3.15 (ILIM_LO)

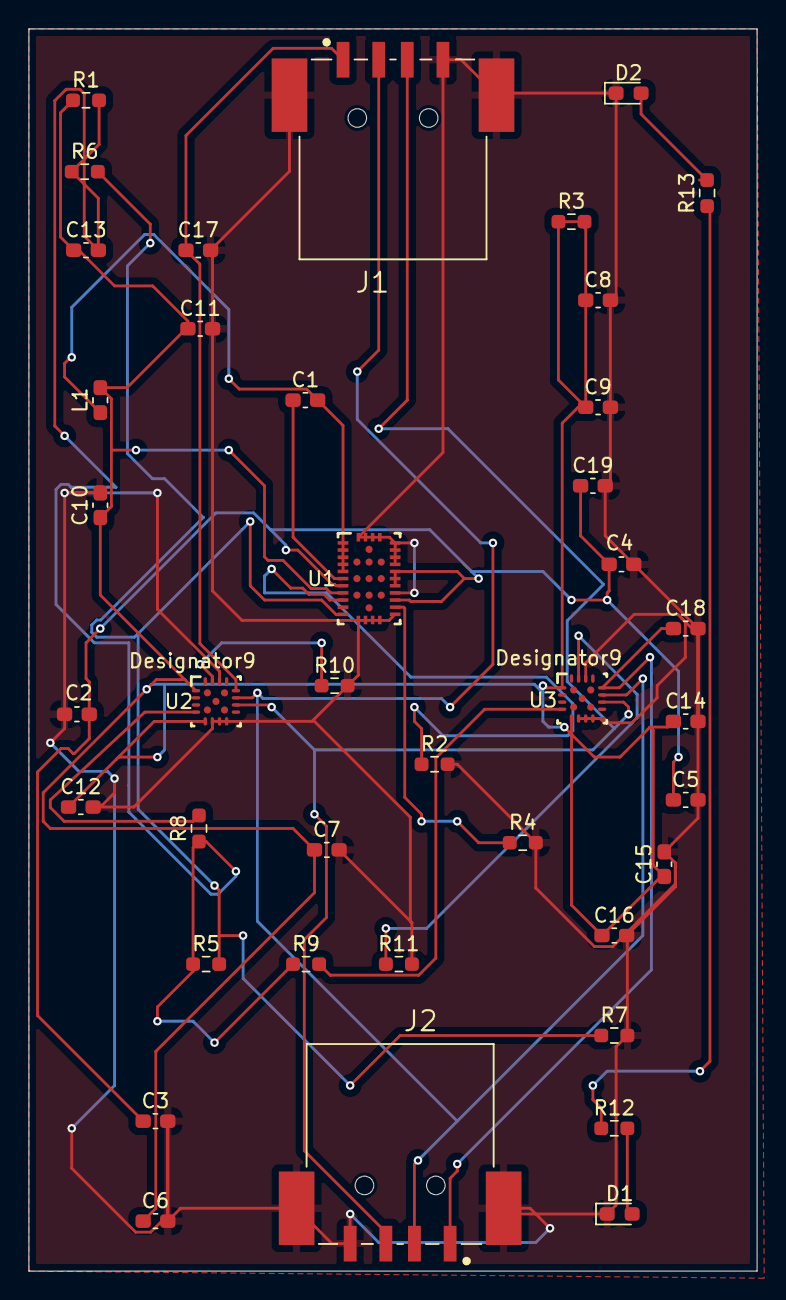
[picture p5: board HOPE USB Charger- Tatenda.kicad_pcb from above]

Board: 2 copper layers, 51.0 x 87.0 mm, 40 parts (0 on the bottom side), 20 nets.
